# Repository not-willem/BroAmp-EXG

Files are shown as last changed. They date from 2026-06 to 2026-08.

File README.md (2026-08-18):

<p align="center">
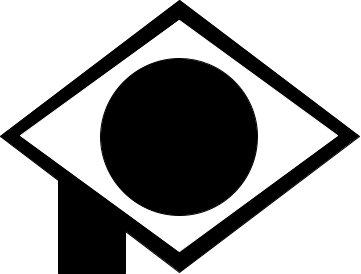
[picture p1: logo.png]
  
</p>

# BroAmp EXG
a decent sized bio amp so i can wire it myself and so that it will be cheaper to produce unlike the other ones on the market partyparrot

go to the website i made [here](https://not-willem.github.io/BroAmp-EXG/)

# overview
BroAmp EXG is an open-source project created by yours truly that allows you to turn different body functions that produce a small amount of electricity and amplify them into a more readable signal.

## features wow
 - same as the BioAmp EXG Pill just easier to produce using cheap parts
 - can do EEG (activity in parts of the brain), EMG (muscle activity, e.g when you move your hand), ECG (heart rate detection) and EOG (eye blink detection)
 - i think you could probably use it for more but thats all that it was listed for on the original page
 - it can send the data back to pretty much any microcontroller with an analog input (ADC)
 - you can configure the gain, bandpass, filter and electrodes all on the board itself

## documentation thumbs up
 - original project: [here](https://github.com/upsidedownlabs/BioAmp-EXG-Pill)
 - date of modifications: June 2026
 - i have made the capacitors and resistors larger to make it easier to hand solder/machine
 - i have changed the board dimensions to 36.5 mm x 48 mm to again, make it easier to hand solder/machine
 - i have kept the same licsense on the hardware (CERN OHL S v2)
 - i have acknowledged the source on the silkscreen
 - the complete source for the modified design is in this github that you're reading this from

## using the project files
To use the project files provided, download them using the green "Code" button at the top of the page, then Download Zip. All the PCB production files are kept in the "production" folder apart from the BOM.csv which is kept in the main folder. 

## production notes
the only thing you should need to do more micro-soldering for is the main chip itself and the electrodes and bandpass filters. these are optional and you will need to micro solder that on but they are for configuration, which, to be fair you could probably also do on the microcontroller itself. The components can simply be hand soldered and they are spaced apart well enough to not short out in case the wires are touching if you've gotten a bigger capacitor/resistor

thanks to the project by [upsidedownlabs](https://github.com/upsidedownlabs/BioAmp-EXG-Pill) because it was super good and cool. clapping

software demos [here](https://github.com/upsidedownlabs/BioAmp-EXG-Pill#software)

you can find the pcb files in the production folder

and [here](https://github.com/not-willem/BroAmp-EXG/blob/main/BOM%20and%20notes.csv) some notes and a BOM that you can put straight into LCSC to get the parts

but yeah heres some photos

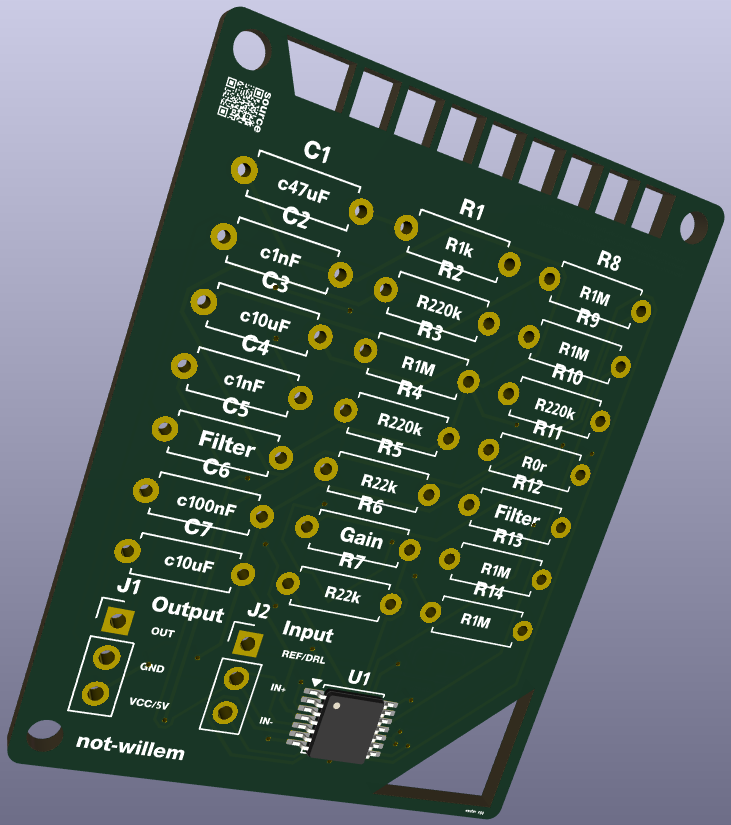
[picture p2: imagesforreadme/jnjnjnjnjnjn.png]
front

oh hello there
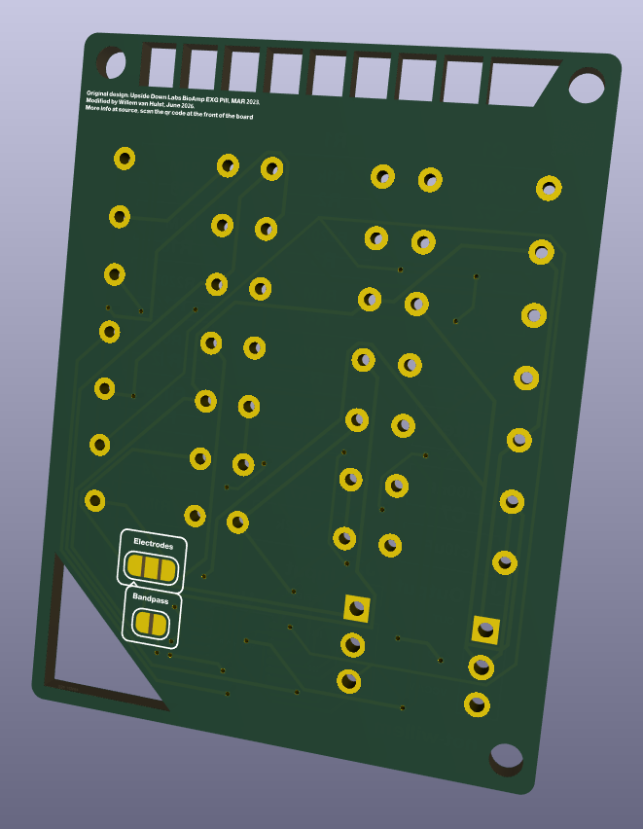
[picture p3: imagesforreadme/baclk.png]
back


Also some wiring stuff

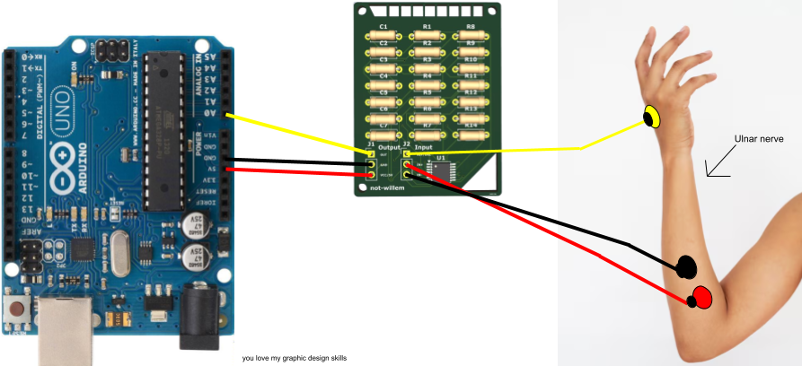
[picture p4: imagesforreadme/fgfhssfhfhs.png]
iamge2


also theres more ways you can use this [here](https://github.com/upsidedownlabs/BioAmp-EXG-Pill/tree/main/graphics/circuits/v1.0), its the same pins to wire they're not called anything different.

I haven't actually built it YET (i'll update this when i do) but i've 3d printed a prototype so you can see the size of it
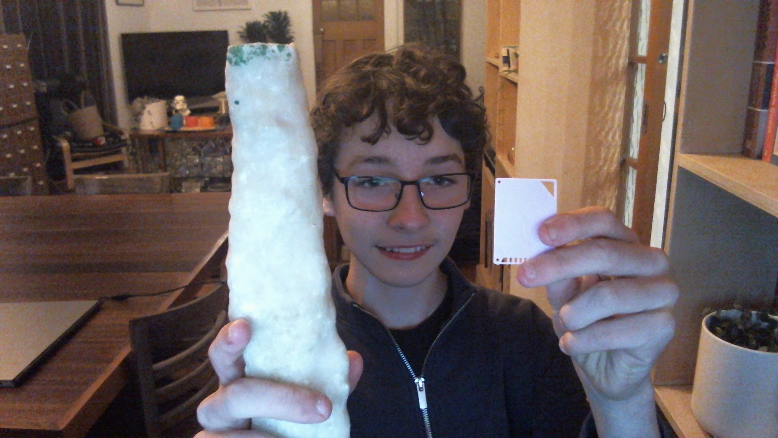
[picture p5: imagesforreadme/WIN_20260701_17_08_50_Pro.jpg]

*stalagmite for scale

okay i think i need a hot plate for soldering the smd part but i cant get funded for it so i'll find alternative ways to do it

alright you can just use a heat gun awesome

ALSO big news everyone the total cost of parts per board comes in at around $12.17 NZD so hooray!

that's quite cheap compared to the $59.61 NZD for ONE from the actual website (btw you HAVE to buy 2 you can't just get one)

P.S reading it again it seems the kit i'm refering to comes with "Two BioAmp EXG Pill boards, 15 gel electrodes, four 3-pin angled pin headers, four 3-pin straight pin headers, six alligator clips, and two 1.5 mm electrode cables" but still I find it a little silly you can't just buy the boards themselves

Anyway I really hope you like this project and consider supporting me by starring this project and if you think you'd want to change anything you can fork the project then make a pull request

##### This design is released under the CERN Open Hardware Licence Version 2 - Strongly Reciprocal (CERN-OHL-S-2.0). hectarelitre

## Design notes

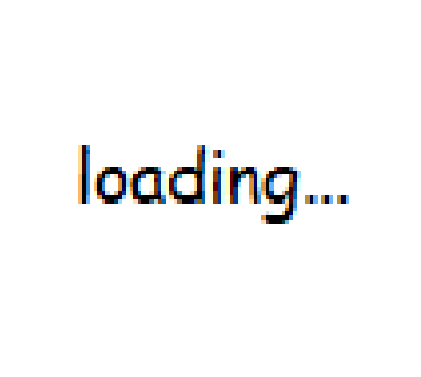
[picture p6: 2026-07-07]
loading.png

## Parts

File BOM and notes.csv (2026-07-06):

Names for me | LCSC Links | Final Clean | Quantity FOR ONE BOARD |  |  | LCSC Part Number | Quantity
C100nF | https://www.lcsc.com/product-detail/C5632430.html | C5632430 | 1 |  |  | C5632430 | 5
C10uF | https://www.lcsc.com/product-detail/C454418.html | C454418 | 2 |  |  | C454418 | 10
C10uF | https://www.lcsc.com/product-detail/C454418.html | C2887266 | 2 |  |  | C2887266 | 10
C1nF | https://www.lcsc.com/product-detail/C2887266.html | C397097 | 1 |  |  | C397097 | 5
C1nF | https://www.lcsc.com/product-detail/C2887266.html | C173063 | 1 |  |  | C173063 | 5
C47uF | https://www.lcsc.com/product-detail/C397097.html | C57435 | 1 |  |  | C57435 | 5
R0r | https://www.lcsc.com/product-detail/C173063.html | C173145 | 5 |  |  | C173145 | 25
R1k | https://www.lcsc.com/product-detail/C57435.html | C479385 | 3 |  |  | C479385 | 15
R1M | https://www.lcsc.com/product-detail/C173145.html | C119354 | 2 |  |  | C119354 | 10
R1M | https://www.lcsc.com/product-detail/C173145.html | C4370424 | 1 |  |  | C4370424 | 5
R1M | https://www.lcsc.com/product-detail/C173145.html
R1M | https://www.lcsc.com/product-detail/C173145.html
R1M | https://www.lcsc.com/product-detail/C173145.html |  |  |  |  | Total (five broamps) |  |  |  |  | Total (5, NZD)
R220k | https://www.lcsc.com/product-detail/C479385.html |  | Total parts (including shipping to nz through lcsc) |  |  | 28.05 | USD | Total parts (including shipping to nz through lcsc) |  |  | 49.15 | NZD
R220k | https://www.lcsc.com/product-detail/C479385.html |  |  | Total PCB (with shipping to nz) |  | 16.1 | USD |  | Total PCB (with shipping to nz) |  | 28.21 | NZD
R220k | https://www.lcsc.com/product-detail/C479385.html
R22k | https://www.lcsc.com/product-detail/C119354.html |  |  |  | total for 5: | 44.15 |  |  |  | total for 5: | 77.36 | NZD
R22k | https://www.lcsc.com/product-detail/C119354.html |  |  |  | total (for selling, etc) for 1 |  | 8.83 |  |  | total (for selling, etc) for 1 |  | 15.472 | NZD
TL074HIPWR | https://www.lcsc.com/product-detail/C4370424.html
 | * please note that i designed the pcb so that you can solder quite a few sizes of capacitors and resistors they may just require extra vertical space/wire
 | for the resistors and capacitors you can use some pretty standard parts
 | but yeah i proabably wouldn't get the capacitors and resistors manufactured as you will need to bend the wires to fit in the holes but i would get the board machined. If i'm going to sell this I can solder the capacitors and resistors myself :)

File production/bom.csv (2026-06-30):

Designator | Footprint | Quantity | Value | LCSC Part #
_2 | SolderJumper-3_P1.3mm_Open_RoundedPad1.0x1.5mm | 1 | SolderJumper_3_Open
 | SolderJumper-2_P1.3mm_Open_RoundedPad1.0x1.5mm | 1 | SolderJumper_2_Open
C1 | R_Axial_DIN0207_L6.3mm_D2.5mm_P7.62mm_Horizontal | 1 | 47uF
C2, C4 | R_Axial_DIN0207_L6.3mm_D2.5mm_P7.62mm_Horizontal | 2 | 1nF
C3, C7 | R_Axial_DIN0207_L6.3mm_D2.5mm_P7.62mm_Horizontal | 2 | 10uF
C5 | R_Axial_DIN0207_L6.3mm_D2.5mm_P7.62mm_Horizontal | 1 | BPFC_C
C6 | R_Axial_DIN0207_L6.3mm_D2.5mm_P7.62mm_Horizontal | 1 | 100nF
J1 | PinHeader_1x03_P2.54mm_Vertical | 1 | BioAmp Output
J2 | PinHeader_1x03_P2.54mm_Vertical | 1 | BioAmp Input
R1 | R_Axial_DIN0207_L6.3mm_D2.5mm_P7.62mm_Horizontal | 1 | 1K
R10, R2, R4 | R_Axial_DIN0207_L6.3mm_D2.5mm_P7.62mm_Horizontal | 3 | 220K
R11 | R_Axial_DIN0207_L6.3mm_D2.5mm_P7.62mm_Horizontal | 1 | 0R
R12 | R_Axial_DIN0207_L6.3mm_D2.5mm_P7.62mm_Horizontal | 1 | BPFC_R
R13, R14, R3, R8, R9 | R_Axial_DIN0207_L6.3mm_D2.5mm_P7.62mm_Horizontal | 5 | 1M
R5, R7 | R_Axial_DIN0207_L6.3mm_D2.5mm_P7.62mm_Horizontal | 2 | 22K
R6 | R_Axial_DIN0207_L6.3mm_D2.5mm_P7.62mm_Horizontal | 1 | RG
U1 | TSSOP-14_4.4x5mm_P0.65mm | 1 | Amp

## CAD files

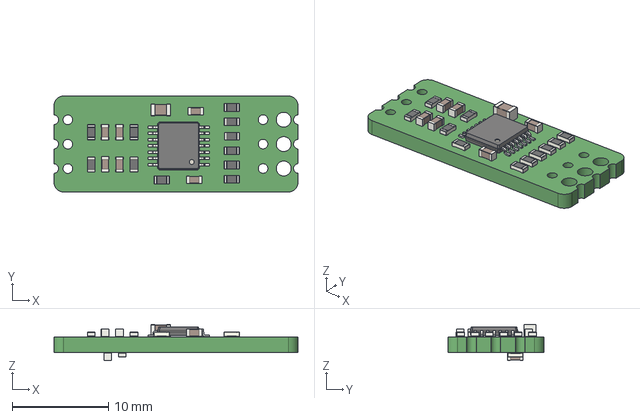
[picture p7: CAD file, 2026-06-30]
component/BioAmp-EXG-Pill.step
25.4 x 10.0 x 3.75 mm

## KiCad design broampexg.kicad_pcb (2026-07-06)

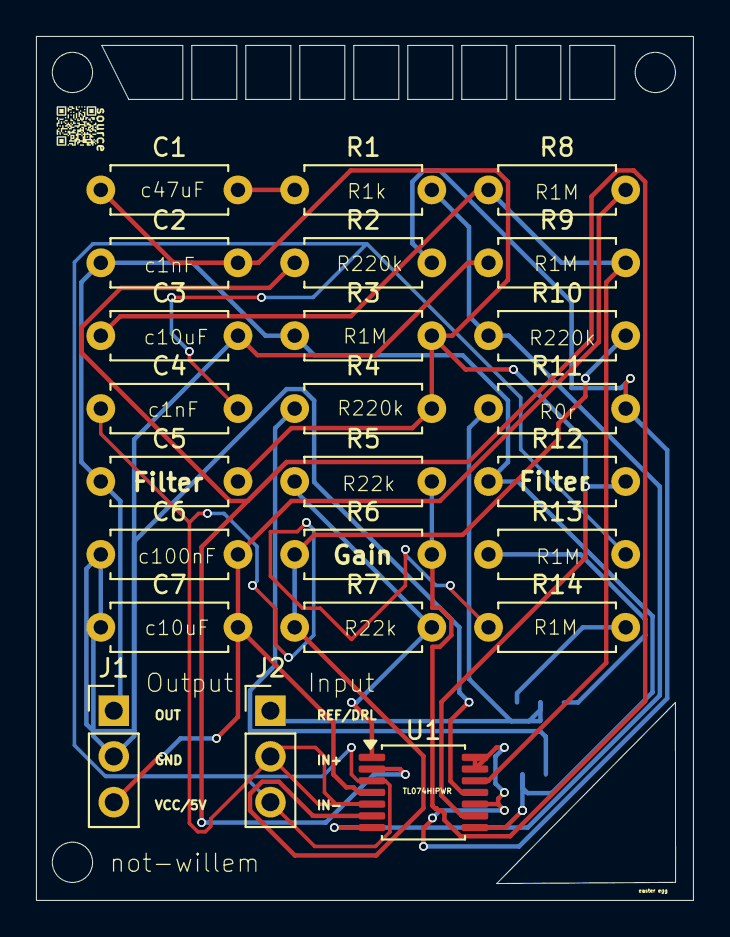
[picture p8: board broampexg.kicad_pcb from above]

Board: 2 copper layers, 36.5 x 48.0 mm, 24 parts (0 on the bottom side), 14 nets.

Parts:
C1: 47uF; R_Axial_DIN0207_L6.3mm_D2.5mm_P7.62mm_Horizontal
C2, C4: 1nF; R_Axial_DIN0207_L6.3mm_D2.5mm_P7.62mm_Horizontal
C3, C7: 10uF; R_Axial_DIN0207_L6.3mm_D2.5mm_P7.62mm_Horizontal
C5: BPFC_C; R_Axial_DIN0207_L6.3mm_D2.5mm_P7.62mm_Horizontal
C6: 100nF; R_Axial_DIN0207_L6.3mm_D2.5mm_P7.62mm_Horizontal
J1: BioAmp Output; PinHeader_1x03_P2.54mm_Vertical
J2: BioAmp Input; PinHeader_1x03_P2.54mm_Vertical
R1: 1K; R_Axial_DIN0207_L6.3mm_D2.5mm_P7.62mm_Horizontal
R2, R4, R10: 220K; R_Axial_DIN0207_L6.3mm_D2.5mm_P7.62mm_Horizontal
R3, R8, R9, R13, R14: 1M; R_Axial_DIN0207_L6.3mm_D2.5mm_P7.62mm_Horizontal
R5, R7: 22K; R_Axial_DIN0207_L6.3mm_D2.5mm_P7.62mm_Horizontal
R6: RG; R_Axial_DIN0207_L6.3mm_D2.5mm_P7.62mm_Horizontal
R11: 0R; R_Axial_DIN0207_L6.3mm_D2.5mm_P7.62mm_Horizontal
R12: BPFC_R; R_Axial_DIN0207_L6.3mm_D2.5mm_P7.62mm_Horizontal
U1: Amp; TSSOP-14_4.4x5mm_P0.65mm

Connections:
DRL: J2.1, R11.1
GND: C3.2, C6.1, C7.1, J1.2, R9.1, U1.11 (V-)
IN+: C4.1, J2.2, R14.1, U1.5 (+)
IN-: C4.2, J2.3, R13.2, U1.3 (+)
unnamed: C1.2, R1.1
unnamed: R5.1, R7.2, U1.1
unnamed: R2.1, R5.2, R6.2, U1.2 (-)
unnamed: R6.1, R7.1, R10.2, U1.6 (-)
unnamed: C3.1, R8.1, R9.2, U1.12 (+)
VCC: C6.2, C7.2, J1.3, R8.2, U1.4 (V+)
ampRef: R2.2, R11.2, U1.10 (+), U1.13 (-), U1.14
bpfIN: C1.1, C2.2, C5.2, R3.2, R4.2, R12.2, U1.9 (-)
bpfOUT: C2.1, C5.1, J1.1, R3.1, R12.1, U1.8
inaOUT: R1.2, R10.1, U1.7

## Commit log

2026-06-30 added in all the files yay
    free
    [BioAmp-EXG-Pill.step, bom.csv, broampexg.kicad_pcb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]
2026-06-30 fonts and stuff yay
    [broampexg.kicad_pcb]
2026-07-01 wiring
    wow
2026-07-01 wiriirtn ghh
    ddgdgdga
2026-07-01 doorman doormouse doorstop doordash doorframe doorway doorknob doormat
    dooor dor dor
    [broampexg.kicad_pcb]
2026-07-03 named the caps and res
    doorman doorstop doormouse doorframe doorknob doordash
    [broampexg.kicad_pcb]
2026-07-04 named again
    [broampexg.kicad_pcb]
2026-07-05 bom and notes
    added my BOM and some notes on the project that could be useful
    [BOM and notes.csv]
2026-07-05 added the link to the BOM and notes
    yay
2026-07-06 im not a tennis man
    [broampexg.kicad_pcb]
2026-07-06 we are the earth today but not yesterday but the app isn't working but my friends are a little bit more
    [broampexg.kicad_pcb]
2026-07-06 added source qr on pcb
    hooray!
    [broampexg.kicad_pcb]
2026-07-06 i think i got the wrong license 💀 lmaooo
    fixed it tho
2026-07-06 ooh wah doo wap doopity doo
    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
    [broampexg.kicad_pcb]
2026-07-08 added really cool POLISHED BOM
    polish
    [BOM - Sheet1 (2).csv]
2026-07-08 added POLISHED BOM so yay
    BOM BOM BOM
    POLISH IS HERE
    [BOM.csv]
2026-07-13 kicad locks are annyoyoyoying
2026-08-14 BOM for solder equipment
    [BOM - Sheet1 (3).csv]
2026-08-14 Update BOM - Solder Equipment.csv
    [BOM - Solder Equipment.csv]
